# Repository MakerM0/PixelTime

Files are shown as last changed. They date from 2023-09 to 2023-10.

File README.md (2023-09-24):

<p align="center">
    <br>
    
    <br>
</p>
<p align="center">   
    
      
</p>

# [PixelTime](https://oshwhub.com/kakaka/PixelTime)
a low power led watch based on ESP32-C3 & MicroPython

[afdian.net](https://afdian.net/a/modular)    [bilibili](https://www.bilibili.com/video/BV1Bj411i7ZR/)   [OSHWHUB](https://oshwhub.com/kakaka/PixelTime)

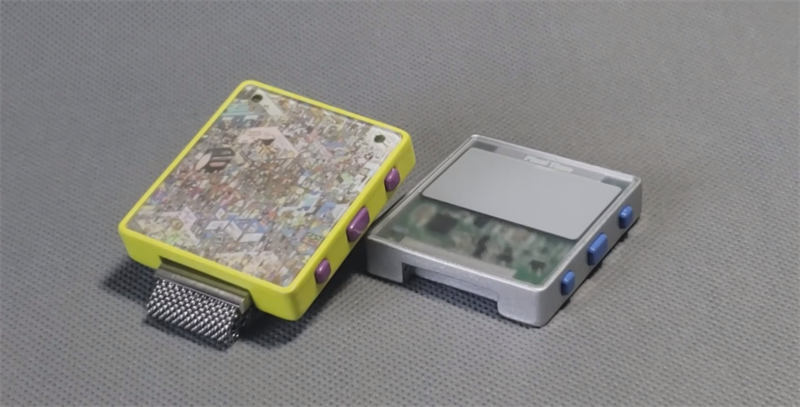
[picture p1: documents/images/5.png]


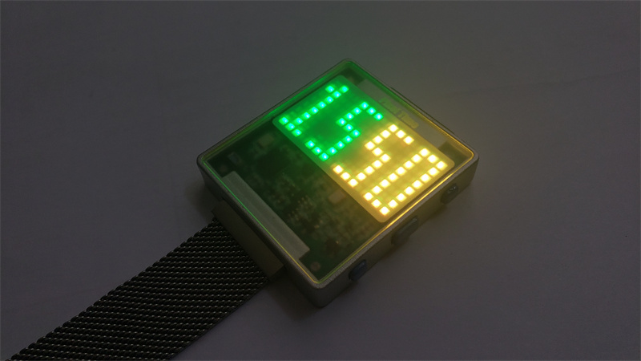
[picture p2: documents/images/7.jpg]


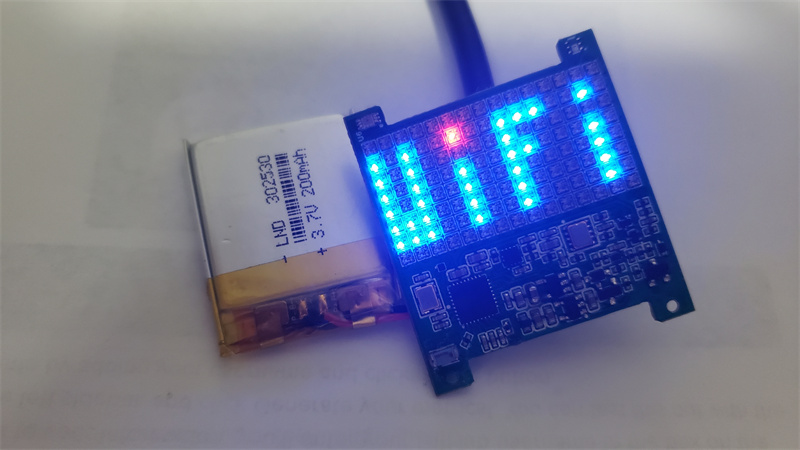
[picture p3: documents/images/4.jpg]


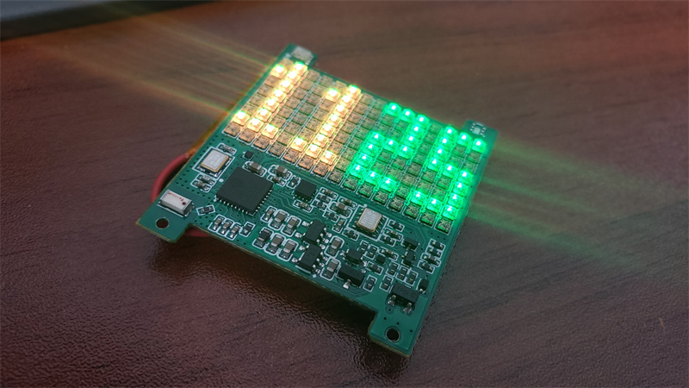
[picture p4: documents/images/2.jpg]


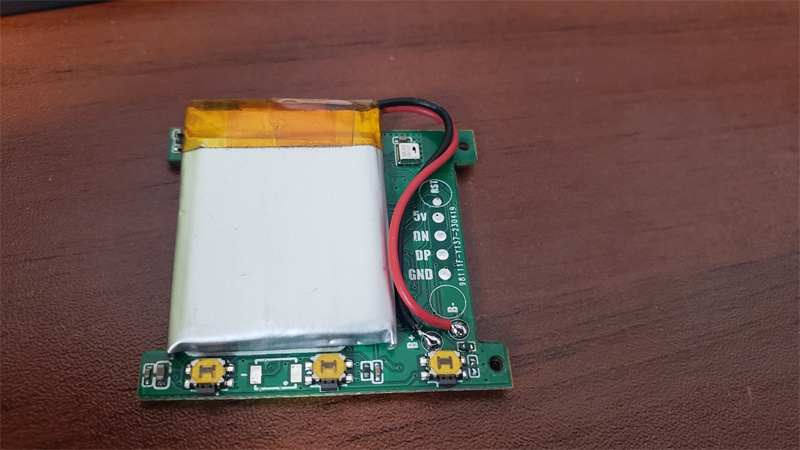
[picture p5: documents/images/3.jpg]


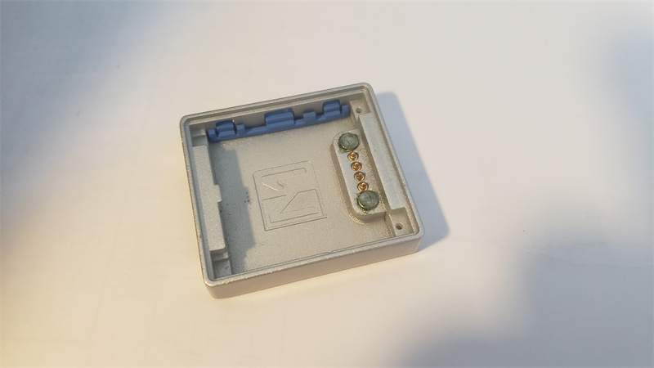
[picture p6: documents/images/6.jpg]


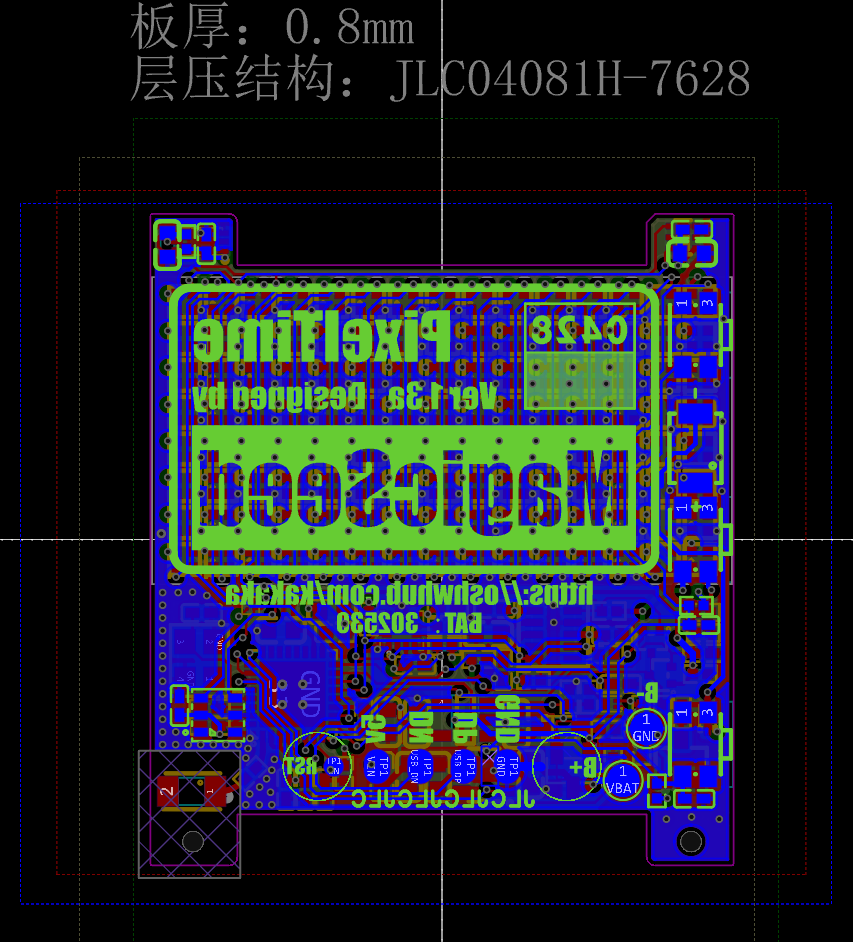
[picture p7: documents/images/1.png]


## Software

based on MicroPython

## Mechanical

## License

(hardware/mechanical)[Creative Commons — Attribution-NonCommercial-ShareAlike 4.0 International — CC BY-NC-SA 4.0](https://creativecommons.org/licenses/by-nc-sa/4.0/)

## Extra

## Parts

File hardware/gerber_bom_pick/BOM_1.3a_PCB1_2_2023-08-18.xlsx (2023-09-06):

No. | Quantity | Designator | Footprint | Manufacturer Part | Manufacturer | Supplier | Supplier Part | Value | Comment | JLCPCB Part Class
1 | 1 | BUZZER2 | BUZ-SMD_L4.0-W3.0-LS4.5-FD | DET402 |  | LCSC | C2911630 |  | DET402 | Extended Part
2 | 2 | C1,C2 | C0402 | 0402CG180J500NT | FH(风华) | LCSC | C1549 | 18pF | 18pF | Basic Part
3 | 13 | C3,C7,C9,C10,C11,C12,C22,C23,C24,C27,C29,C33,C34 | C0402_NEW | CL05B104KO5NNNC | SAMSUNG(三星) | LCSC | C1525 | 100nF | 100nF | Basic Part
4 | 1 | C4 | C0603 | CL10A475KO8NNNC | SAMSUNG(三星) | LCSC | C19666 | 4.7uF | 4.7uF | Basic Part
5 | 6 | C5,C15,C16,C17,C18,C35 | C0603 | CL10A106KP8NNNC | SAMSUNG(三星) | LCSC | C19702 | 10uF | 10uF | Basic Part
6 | 4 | C6,C8,C25,C28 | C0603 | CL10A105KB8NNNC | SAMSUNG(三星) | LCSC | C15849 | 1uF | 1uF | Basic Part
7 | 1 | C30 | C0402 | CL05A105KP5NNNC | SAMSUNG(三星) | LCSC | C14445 | 1uF | 1uF | Extended Part
8 | 2 | C31,C36 | C0402 | CC0402KRX7R7BB104 | YAGEO(国巨) | LCSC | C60474 | 100nF | 100nF | Extended Part
9 | 1 | C37 | C0402 | CL05A475MP5NRNC | SAMSUNG(三星) | LCSC | C23733 | 4.7uF | 4.7uF | Basic Part
10 | 1 | D1 | SOD-323_L1.8-W1.3-LS2.5-RD | 1N5819WS | Hottech(合科泰) | LCSC | C191023 |  | 1N5819WS | Basic Part
11 | 1 | D2 | SOT-523-3_L1.6-W0.8-P1.00-LS1.6-BR | DAN222 | CJ(江苏长电/长晶) | LCSC | C68999 |  | DAN222 | Extended Part
12 | 1 | D3 | SOD-523_L1.2-W0.8-LS1.6-RD | 1N4148WT | onsemi(安森美) | LCSC | C232841 |  | 1N4148WT | Extended Part
13 | 1 | L1 | L0603 | UPZ1608E101-3R0TF | Sunlord(顺络) | LCSC | C96995 |  | UPZ1608E101-3R0TF | Extended Part
14 | 1 | L2 | ANT-SMD_L3.2-W1.6-A | AN3216-245 | rainsun(霖昱微) | LCSC | C2916136 |  | AN3216-245 | Extended Part
15 | 120 | LED1,LED2,LED3,LED4,LED5,LED6,LED7,LED8,LED9,LED10,LED11,LED12,LED13,LED14,LED15,LED16,LED17,LED18,LED19,LED20,LED21,LED22,LED23,LED24,LED25,LED26,LED27,LED28,LED29,LED30,LED31,LED32,LED33,LED34,LED35,LED36,LED37,LED38,LED39,LED40,LED41,LED42,LED43,LED44,LED45,LED46,LED47,LED48,LED49,LED50,LED51,LED52,LED53,LED54,LED55,LED56,LED57,LED58,LED59,LED60,LED61,LED62,LED63,LED64,LED65,LED66,LED67,LED68,LED69,LED70,LED71,LED72,LED73,LED74,LED75,LED76,LED77,LED78,LED79,LED80,LED81,LED82,LED83,LED84,LED85,LED86,LED87,LED88,LED89,LED90,LED91,LED92,LED93,LED94,LED95,LED96,LED97,LED98,LED99,LED100,LED101,LED102,LED103,LED104,LED105,LED106,LED107,LED108,LED109,LED110,LED111,LED112,LED113,LED114,LED115,LED116,LED117,LED118,LED119,LED120 | LED-SMD_4P-L1.5-W1.5 | DY-S1515065/RGBC/6805-5T | TONYU(东裕) | LCSC | C524053 |  | DY-S1515065/RGBC/6805-5T | Extended Part
16 | 1 | Q1 | SOT-25-5_L3.0-W1.8-P0.95-LS3.0-BR | XC6220B331MR-G | TOREX(特瑞仕) | LCSC | C86534 |  | XC6220B331MR-G | Extended Part
17 | 1 | Q2 | SOT-23_L2.9-W1.3-P1.90-LS2.4-BR | AO3400A | BORN伯恩半导体 | LCSC | C344010 |  | AO3400A | Extended Part
18 | 1 | Q3 | SOT-23-3_L2.9-W1.3-P1.90-LS2.4-BR | AO3415 | Hottech(合科泰) | LCSC | C181094 |  | AO3415 | Extended Part
19 | 1 | Q5 | DFN1006-3_L1.0-W0.6-P0.35-BR_BC846BM | HSBG2103 | HUASHUO(华朔) | LCSC | C845598 |  | HSBG2103 | Extended Part
20 | 9 | R1,R2,R7,R12,R14,R15,R22,R24,R25 | R0402 | 0402WGF1002TCE | UNI-ROYAL(厚声) | LCSC | C25744 | 10kΩ | 10kΩ | Basic Part
21 | 3 | R3,R10,R11 | R0402 | 0402WGF0000TCE | UNI-ROYAL(厚声) | LCSC | C17168 | 0Ω | 0Ω | Basic Part
22 | 2 | R5,R6 | R0402 | 0402WGF1001TCE | UNI-ROYAL(厚声) | LCSC | C11702 | 1kΩ | 1kΩ | Basic Part
23 | 3 | R8,R17,R18 | R0402 | 0402WGF1003TCE | UNI-ROYAL(厚声) | LCSC | C25741 | 100kΩ | 100kΩ | Basic Part
24 | 2 | R13,R27 | R0402 | 0402WGF4703TCE | UNI-ROYAL(厚声) | LCSC | C25790 | 470kΩ | 470kΩ | Basic Part
25 | 1 | R16 | R0402 | 0402WGF200JTCE | UNI-ROYAL(厚声) | LCSC | C25089 | 20Ω | 20Ω | Extended Part
26 | 2 | R23,R28 | R0402 | 0402WGF1004TCE | UNI-ROYAL(厚声) | LCSC | C26083 | 1MΩ | 1MΩ | Basic Part
27 | 1 | R29 | R0402 | 0402WGF3001TCE | UNI-ROYAL(厚声) | LCSC | C25784 |  | 0402WGF3001TCE | Extended Part
28 | 3 | SW1,SW2,SW3 | SW-SMD_ST-1186BM | ST-1186BM | RISHENG(日昇) | LCSC | C589196 |  | ST-1186BM | Extended Part
29 | 1 | U1 | QFN-32_L5.0-W5.0-P0.50-TL-EP3.7 | ESP32-C3FH4 | ESPRESSIF 乐鑫 | LCSC | C2858491 |  | ESP32-C3FH4 | Extended Part
30 | 1 | U2 | SENSOR-SMD_L3.0-W3.0-P1.00-BR | AHT20 | 广州奥松 | LCSC | C2757850 |  | AHT20 | Extended Part
31 | 1 | U3 | LGA-12_L2.0-W2.0-P0.50-BL | KXTJ3-1057 | ROHM(罗姆) | LCSC | C442603 |  | KXTJ3-1057 | Extended Part
32 | 1 | U4 | SOT-23-5_L3.0-W1.7-P0.95-LS2.8-BR | TP4054-42-SOT25R | TOPPOWER(南京拓微) | LCSC | C32574 |  | TP4054-42-SOT25R | Basic Part
33 | 1 | U6 | WSOF-6_L2.6-W1.6-P0.50-BL | BH1715FVC-TR | ROHM(罗姆) | LCSC | C79632 |  | BH1715FVC-TR | Extended Part
34 | 1 | U7 | WLCSP-4_L0.8-W0.8-R2-C2-P0.40-BL | QMC6308 | QST(上海矽睿) | LCSC | C462705 |  | QMC6308 | Extended Part
35 | 1 | U9 | OSC-SMD_10P-L3.2-W2.5-BL-1 | RX8111CE | EPSON(爱普生) | LCSC | C2929261 |  | RX8111CE | Extended Part
36 | 1 | U11 | SENSOR-SMD_LTR-390UV-01 | LTR-390UV-01 | LITEON(台湾光宝) | LCSC | C492374 |  | LTR-390UV-01 | Extended Part
37 | 1 | X1 | OSC-SMD_4P-L3.2-W2.5-BL_SIT8008BI | X322540MPB4SI | YXC扬兴科技 | LCSC | C9010 | 40MHz | 40MHz | Extended Part

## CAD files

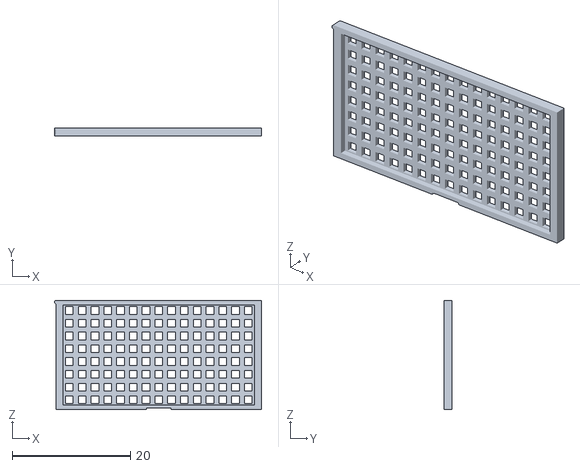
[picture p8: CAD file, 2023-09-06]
mechanical/stl/压板.stl
34.9 x 1.35 x 18.5

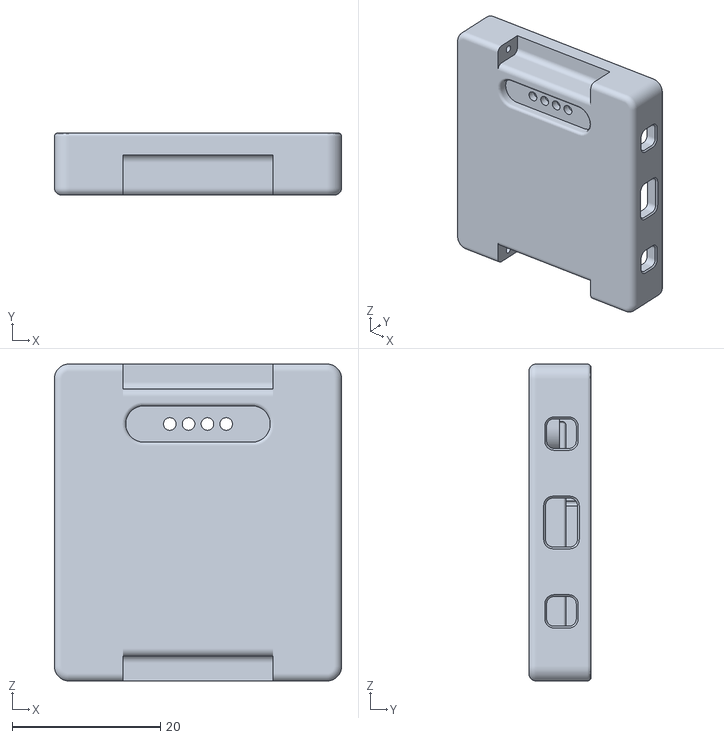
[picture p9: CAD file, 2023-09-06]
mechanical/stl/外壳.stl
38.8 x 8.40 x 42.8

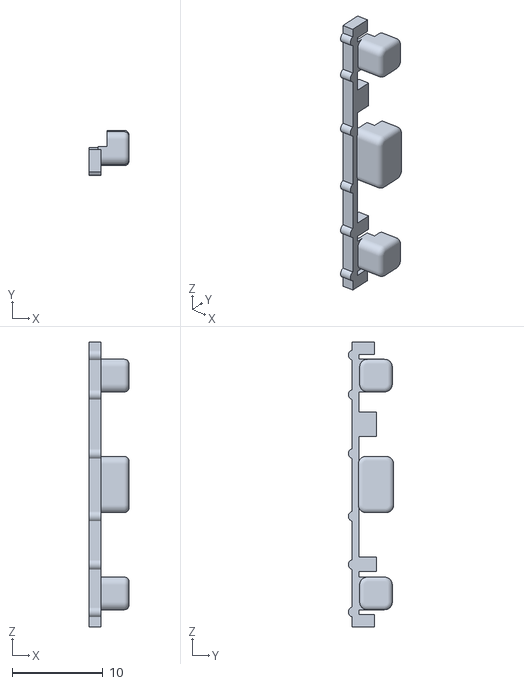
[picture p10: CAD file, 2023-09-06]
mechanical/stl/按键.stl
4.40 x 5.00 x 31.4

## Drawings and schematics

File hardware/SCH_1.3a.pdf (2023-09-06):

Ambient Light | ACC | UV

# Magnetic

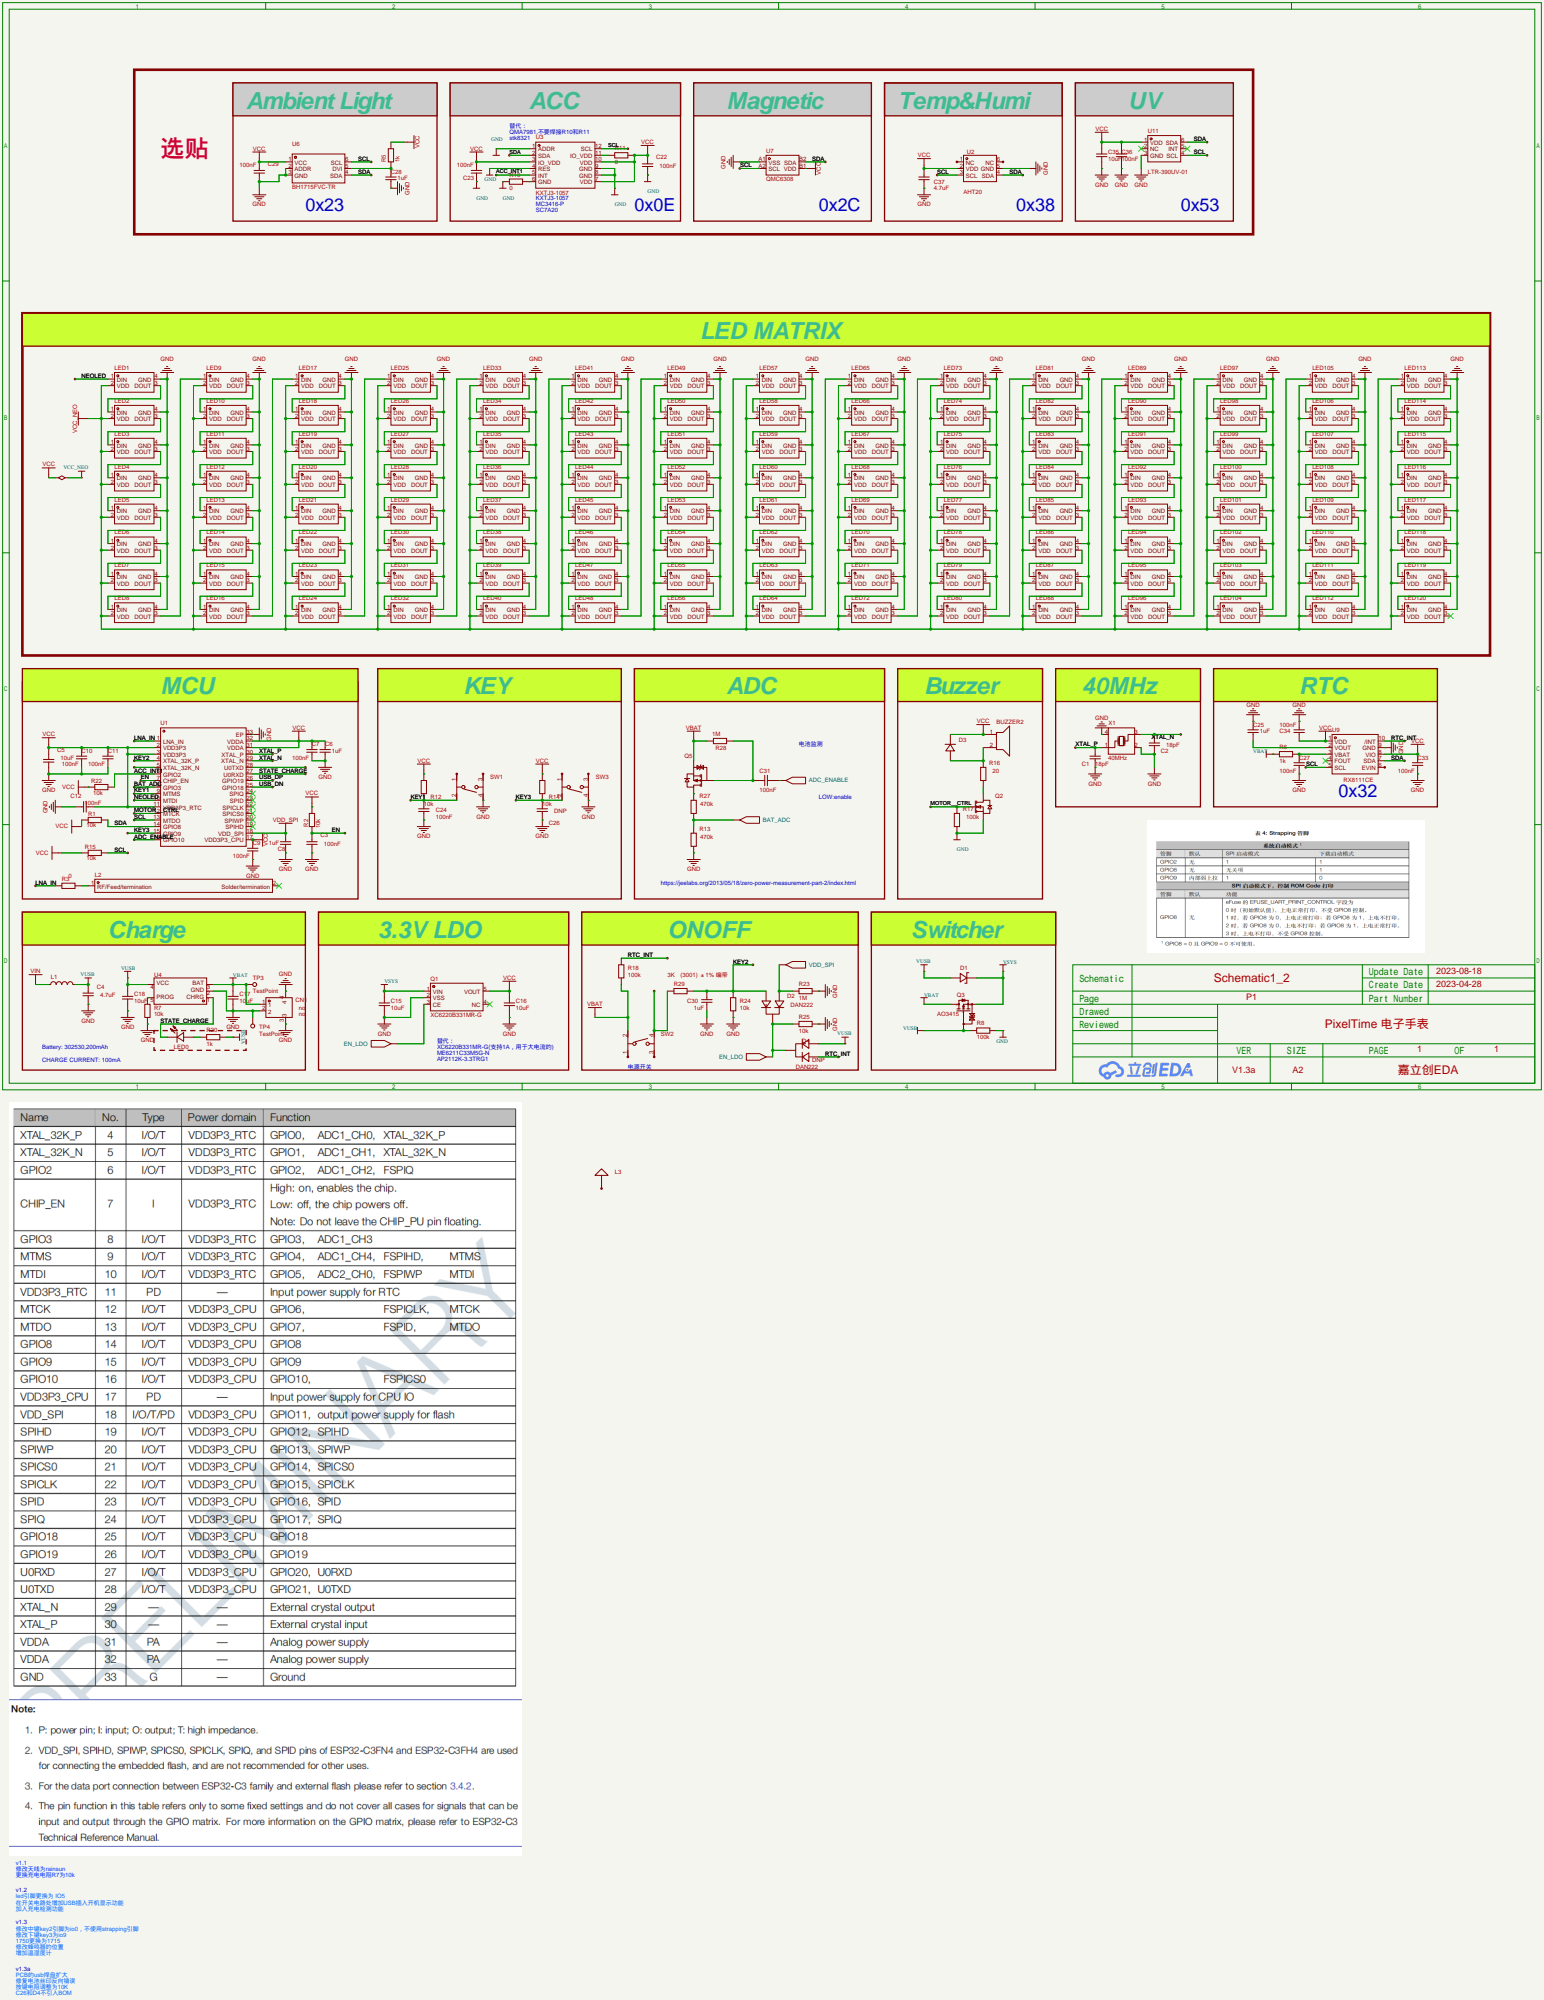
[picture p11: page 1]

https://jeelabs.org/2013/05/18/zero-power-measurement-part-2/index.html

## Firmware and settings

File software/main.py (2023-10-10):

 
from machine import I2C, Pin
import time
import network 
import neopixel 
import gc
import bitmapfont
from font3x8 import *
from week7x7  import * 
import rx8111

import config

ssid = config.ssid
password =config.password

zonetime = 8*3600

NEOPIXEL_PIN = 5
ROWS = 8
COLS = 15
NUMBER_PIXELS = ROWS * COLS

C_BLACK=(0,0,0)
C_GREEN=(0,35,0)
C_BLUE=(0,0,35)
C_RED=(35,0,0)
C_YELLOW=(35,35,0)   
C_MONTH=(31,5,12) 
C_DAY=(35,31,31) 

np = neopixel.NeoPixel(Pin(NEOPIXEL_PIN), NUMBER_PIXELS)




#15x8
ICON_WIFI=(
    0,0,0,0,0,0,0,0,0,0,0,0,0,0,0,
    1,0,1,0,0,1,0,0,1,1,1,0,0,1,0,
    1,0,1,0,0,0,0,0,1,0,0,0,0,0,0,
    1,0,1,0,0,1,0,0,1,1,0,0,0,1,0,
    1,0,1,0,0,1,0,0,1,0,0,0,0,1,0,
    1,1,1,0,0,1,0,0,1,0,0,0,0,1,0,
    1,1,1,0,0,1,0,0,1,0,0,0,0,1,0,
    0,0,0,0,0,0,0,0,0,0,0,0,0,0,0,

)
 
class Display(object):
    def __init__(self,np):
        self.np=np

    
    def write_pixel(self,x,y,value):
        if y >= 0 and y < ROWS and x >=0 and x < COLS:
            self.np[x*ROWS + y] = value

    def drawPixel(self,x,y,value):
        self.write_pixel(x,y,value)

        
            
    def clear(self):
        for i in range(NUMBER_PIXELS):
            np[i]=(0,0,0)            
        self.np.write()
    
    def show(self):
        self.np.write()

    def draw1Num(self,x,y,num,color,bg=None):
        num=num%10
        for j in range(8):
            for i in range(3):
                if  FONT3X8[num][i+j*3]==1:
                    self.write_pixel(x+i,y+j,color)
                else :
                    if bg != None:
                        self.write_pixel(x+i,y+j,bg)
                    
    def drawNum(self,x,y,num,color,bg=None)  :
        self.draw1Num(x,y,num//1000%10,color,bg)
        self.draw1Num(x+4,y,num%1000//100,color,bg)
        self.draw1Num(x+4*2,y,num%100//10,color,bg)
        self.draw1Num(x+4*3,y,num%10,color,bg)
        
    def change1Num(self,x,y,num_src,num_dest,color,bg=None):
        num_src=num_src%10
        num_dest=num_dest%10
        
        for i in range(1,9):
            self.draw1Num(x,y-i,num_src,color,bg)
            self.draw1Num(x,y+8-i,num_dest,color,bg)
            time.sleep(0.01)
            self.show()
    
    def draw1Week(self,x,y,num,color,bg=None):   
        for j in range(8):
            for i in range(7):
                if  WEEK7X8[num][i+j*7]==1:
                    self.write_pixel(x+i,y+j,color)
                else :
                    if bg != None:
                        self.write_pixel(x+i,y+j,bg)
    
    def drawWeek(self,x,y,watch,color,bg=None)  :
        # num=num%7
        # print(num)
        self.draw1Week(x,y,7,color,bg)
        self.draw1Week(x+8,y,watch.time_now[6],color,bg) 
    
    def drawTime(self,x,y,watch,color1,color2,bg=None): 
        self.draw1Num(x+0,y,watch.time_now[3]//10,color1,bg)
        self.draw1Num(x+4,y,watch.time_now[3]%10,color1,bg)
        self.draw1Num(x+8,y,watch.time_now[4]//10,color2,bg)
        self.draw1Num(x+12,y,watch.time_now[4]%10,color2,bg)
        self.show()
    
    def drawDate(self,x,y,watch,color1,color2,bg=None):
        if  watch.time_now[1]//10:
            self.draw1Num(x+0,y,watch.time_now[1]//10,color1,bg)
        else:
            self.draw1Num(x+0,y,watch.time_now[1]//10,bg,bg)

        self.draw1Num(x+4,y,watch.time_now[1]%10,color1,bg)
        if  watch.time_now[2]//10:            
            self.draw1Num(x+8,y,watch.time_now[2]//10,color2,bg)
        else:
            self.draw1Num(x+8,y,watch.time_now[2]//10,bg,bg)
        self.draw1Num(x+12,y,watch.time_now[2]%10,color2,bg)
        self.show()
    
    def drawIcon(self,x,y,width,height,icon,color,bg=None):
        for j in range(height):
            for i in range(width):
                if  icon[i+j*width]==1:
                    self.write_pixel(x+i,y+j,color)
                else :
                    if bg != None:
                        self.write_pixel(x+i,y+j,bg)




disp = Display(np)

import machine
class Watch(object):
    def __init__(self,time_now):
        self.time_now=time_now
        self.time_old=time_now
        self.timeout=0 #关机超时时间，ms单位
        self.timeout_stamp=time.ticks_ms()
        

    def resetTimeout(self,timeout=5000):
        self.timeout= timeout
        self.timeout_stamp=time.ticks_ms()

    def checkTimeout(self): 
        deadline = time.ticks_add(self.timeout_stamp,  self.timeout)
        if time.ticks_diff(deadline, time.ticks_ms()) > 0:
            return False
        else:
             return True


    

     

    def poweroff(self):
        machine.deepsleep()


    


INDEX_HOUR = 3
INDEX_MINUTE = 4
INDEX_SECOND = 5

 

def updateTime(watch):
    watch.time_now = rtc.datetime()
    if watch.time_now != watch.time_old:
        if watch.time_now[INDEX_MINUTE]%10 != watch.time_old[INDEX_MINUTE]%10:
            disp.change1Num(12,0,watch.time_old[INDEX_MINUTE]%10,watch.time_now[INDEX_MINUTE]%10,C_YELLOW,C_BLACK)
            
        if watch.time_now[INDEX_MINUTE]//10 != watch.time_old[INDEX_MINUTE]//10:
            disp.change1Num(8,0,watch.time_old[INDEX_MINUTE]//10,watch.time_now[INDEX_MINUTE]//10,C_YELLOW,C_BLACK)
            
        if watch.time_now[INDEX_HOUR]%10 != watch.time_old[INDEX_HOUR]%10:
            disp.change1Num(4,0,watch.time_old[INDEX_HOUR]%10,watch.time_now[INDEX_HOUR]%10,C_GREEN,C_BLACK)
            
        if watch.time_now[INDEX_HOUR]//10 != watch.time_old[INDEX_HOUR]//10:
            disp.change1Num(0,0,watch.time_old[INDEX_HOUR]//10,watch.time_now[INDEX_HOUR]//10,C_GREEN,C_BLACK)
        
        watch.time_old = watch.time_now


print('rx8111 test')
i2c = I2C(0, scl=Pin(7), sda=Pin(8), freq=400000)
rtc = rx8111.RX8111(i2c)

week=('SUN','MON','TUE','WED','THU','FRI','SAT')
 


def syncTimeByWifi(ssid,password,trycnt=20):
    if ssid == None :
        return
    import ntptime
    wlan = network.WLAN(network.STA_IF)
    wlan.active(True)
    wlan.connect(ssid,password)
    
    if not wlan.isconnected():
        while not wlan.isconnected():
            print("Waiting to connect:")
            time.sleep(1.0)
            trycnt = trycnt-1
            if trycnt%2 :
                disp.drawPixel(5,1,C_GREEN)
            else:
                disp.drawPixel(5,1,C_RED)

            disp.show()
            if trycnt<0:
                print("\nFail !!!\n")
                break
    if wlan.isconnected():     
        print(wlan.ifconfig())
        while True:
            try:
                print('获取时间中')
                ntptime.host = 'ntp1.aliyun.com'
                ntptime.settime()
                print('成功获取')
                break
            except:
                print('获取失败')
                time.sleep(1)
    wlan.disconnect()
    wlan.active(False)
    watch.resetTimeout()



charge = Pin(20, Pin.IN, Pin.PULL_UP)

k1 = Pin(4, Pin.IN)
k2 = Pin(0, Pin.IN)
k3 = Pin(9, Pin.IN)


class Event():
    K1_PRESSED=1
    K1_RELEASED=2
    K2_PRESSED=3
    K2_RELEASED=4
    K3_PRESSED=5
    K3_RELEASED=6
    K1_LONG=7
    K2_LONG=8
    K3_LONG=9

    def __init__(self):
        self.event=[]
    
    def addEvent(self,evt):
        self.event.append(evt)
    
    def getEvent(self):  
        if len(self.event)==0:
            return -1              
        return self.event.pop(0)

LongPressed = 1000       
key_time=0
def fun(key):
    global key_time
    watch.resetTimeout()
    if key==k1:
        if key.value() == 0:
            key_time=time.ticks_ms()
            # print('k1 pressed')
            evt.addEvent(Event.K1_PRESSED) 
        else:
            # print('k1 released')
            if time.ticks_diff(time.ticks_ms(),key_time)>LongPressed:
                evt.addEvent(Event.K1_LONG)
            else:                
                evt.addEvent(Event.K1_RELEASED)
    if key==k2:
        if key.value() == 1:
            # print('k2 pressed')
            evt.addEvent(Event.K2_PRESSED)
        else:
            # print('k2 released')
            evt.addEvent(Event.K2_RELEASED)
    if key==k3:
        if key.value() == 0:
            # print('k3 pressed')
            evt.addEvent(Event.K3_PRESSED)
        else:
            # print('k3 released')   
            evt.addEvent(Event.K3_RELEASED)  
    




k1.irq(fun,Pin.IRQ_FALLING | Pin.IRQ_RISING)
k2.irq(fun,Pin.IRQ_FALLING | Pin.IRQ_RISING)
k3.irq(fun,Pin.IRQ_FALLING | Pin.IRQ_RISING)

currentPage=0


  

# syncTimeByWifi(ssid,password)
# sec=time.mktime(time.localtime())#获取时间戳
# now = time.localtime(sec+zonetime)#获取新时区的时间

# rtc.datetime(now)

evt = Event() 
disp.clear()
 
watch = Watch(rtc.datetime())
 
disp.drawTime( 0,0,watch,C_GREEN,C_YELLOW,C_BLACK)

watch.resetTimeout()

def switchPage():
    global currentPage
    if currentPage==0:
        
        for j in range(8):
            disp.drawTime(0,-1-j,watch,C_GREEN,C_YELLOW,C_BLACK)
            disp.drawWeek(0,7-j,watch,C_GREEN,C_BLACK)
            disp.show()
            time.sleep(0.01)
        currentPage=1
        print(currentPage)
        return

    if currentPage==1:
        for j in range(8):
            disp.drawWeek(0,-1-j,watch,C_GREEN,C_BLACK)
            disp.drawDate(0,7-j,watch,C_MONTH,C_DAY,C_BLACK)
            disp.show()
            time.sleep(0.01)
        currentPage=2
        print(currentPage)
        return

    if currentPage==2:
        for j in range(8):
            disp.drawDate(0,-1-j,watch,C_MONTH,C_DAY,C_BLACK)
            disp.drawTime(0,7-j,watch,C_GREEN,C_YELLOW,C_BLACK)
            disp.show()
            time.sleep(0.01)
        currentPage=0
        print(currentPage)
        return

def handleEvent(evt):
    global currentPage     
    if  evt<=0:
        return
    
    if evt==Event.K2_PRESSED:
        switchPage()
        pass
    if evt==Event.K3_PRESSED:
        watch.poweroff()

    if evt==Event.K1_LONG:
        print('syncTimeByWifi')
 
        disp.drawIcon(0,0,15,8,ICON_WIFI,C_BLUE,C_BLACK)
        disp.show()
        syncTimeByWifi(ssid,password)
        sec=time.mktime(time.localtime())#获取时间戳
        now = time.localtime(sec+zonetime)#获取新时区的时间

        rtc.datetime(now)
        if currentPage ==0:
            disp.drawTime(0,0,watch,C_GREEN,C_YELLOW,C_BLACK)            
            updateTime(watch) 
        elif currentPage ==1:
            disp.drawWeek(0,0,watch,C_GREEN,C_BLACK)
        elif currentPage ==2:
            disp.drawDate(0,0,watch,C_MONTH,C_DAY,C_BLACK)

        disp.show()

        print(now)
        pass

 
 
timeout_en = False

if  charge.value()==0 :
    timeout_en = False
else:
    timeout_en = True


print(timeout_en)

 


while True:
    if  charge.value()==0 :
        time.sleep(1.0)
        disp.clear()
        
    if  watch.checkTimeout() and timeout_en:
        print("timeout")
        watch.poweroff()
        watch.resetTimeout()
     

    handleEvent(evt.getEvent())
    # Calculate deadline for operation and test for it
    deadline = time.ticks_add(time.ticks_ms(), 5000)
    if time.ticks_diff(deadline, time.ticks_ms()) > 0:
        deadline = time.ticks_add(time.ticks_ms(), 5000)
        if currentPage ==0:
            updateTime(watch)

         
    
        # print(watch.time_now)
    time.sleep(0.2)
    gc.collect()
    # print(f'mem: {gc.mem_free()}')

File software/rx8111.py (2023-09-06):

'''
    RX8111 RTC drive
 
    Author: M0dular
    Date:   2023-8-5
    Ver:    0.1.0
 
    https://oshwhub.com/kakaka
'''



from micropython import const
from math import log2
from gc import collect
# bus address 
RX8111_ADDR = const(0x32)

# Basic time and calendar register 
RX8111_SEC = const(0x10)
RX8111_MIN = const(0x11)
RX8111_HOUR = const(0x12)
RX8111_WEEK = const(0x13)
RX8111_DAY = const(0x14)
RX8111_MONTH = const(0x15)
RX8111_YEAR = const(0x16)
RX8111_MIN_ALARM = const(0x17)
RX8111_HOUR_ALARM = const(0x18)
RX8111_WEEK_DAY_ALARM = const(0x19)
RX8111_TIMER_COUNTER0 = const(0x1A)
RX8111_TIMER_COUNTER1 = const(0x1B)
RX8111_TIMER_COUNTER2 = const(0x1C)
RX8111_EXTENREG = const(0x1D)
RX8111_FLAGREG = const(0x1E)
RX8111_CTRLREG = const(0x1F)

RX8111_TIMESTAMP_1_1000S = const(0x20)
RX8111_TIMESTAMP_1_100S = const(0x21)
RX8111_TIMESTAMP_SEC = const(0x22)
RX8111_TIMESTAMP_MIN = const(0x23)
RX8111_TIMESTAMP_HOUR = const(0x24)
RX8111_TIMESTAMP_WEEK = const(0x25)
RX8111_TIMESTAMP_DAY = const(0x26)
RX8111_TIMESTAMP_MONTHS = const(0x27)
RX8111_TIMESTAMP_YEAR = const(0x28)
RX8111_STATUS_STAMP = const(0x29)

RX8111_EVIN_SETTING = const(0x2B)
RX8111_SEC_ALARM = const(0x2C)
RX8111_TIMER_CONTROL = const(0x2D)
RX8111_CMD_TRIG_CTRL = const(0x2E)
RX8111_COMMAND_TRIGGER = const(0x2F)

RX8111_PWR_SWITCH_CTRL = const(0x32)
RX8111_STATUS_MONITOR = const(0x33)
RX8111_TIME_STAMP_BUF_CTRL = const(0x34)
RX8111_TIME_STAMP_TRIG_CTRL = const(0x35)
RX8111_TIME_STAMP_DATA_STATUS = const(0x36)

'''
RX8111_EXT_TSEL0 BIT(0)
RX8111_EXT_TSEL1 BIT(1)
RX8111_EXT_ECP BIT(2)
RX8111_EXT_WADA BIT(3)
RX8111_EXT_TE BIT(4)
RX8111_EXT_USEL BIT(5)
RX8111_EXT_FSEL0 BIT(6)
RX8111_EXT_FSEL1 BIT(7)

RX8111_FLAG_FSTOPF BIT(0)
RX8111_FLAG_VLF BIT(1)
RX8111_FLAG_EVF BIT(2)
RX8111_FLAG_AF BIT(3)
RX8111_FLAG_TF BIT(4)
RX8111_FLAG_UF BIT(5)
RX8111_FLAG_PORF BIT(7)
'''
RX8111_CTRL_STOP =const(0)
'''
RX8111_CTRL_EIE BIT(2)
RX8111_CTRL_AIE BIT(3)
RX8111_CTRL_TIE BIT(4)
RX8111_CTRL_UIE BIT(5)

RX8111_EVIN_EOVEN BIT(1)
RX8111_EVIN_EPRUP_SEL0 BIT(2)
RX8111_EVIN_EPRUP_SEL1 BIT(3)
RX8111_EVIN_EPRDW_SEL BIT(4)
RX8111_EVIN_ET0 BIT(5)
RX8111_EVIN_ET1 BIT(6)
RX8111_EVIN_EHL BIT(7)

RX8111_TIMER_CTRL_TSTP BIT(0)
RX8111_TIMER_CTRL_TMPIN BIT(1)
RX8111_TIMER_CTRL_TBKE BIT(2)
RX8111_TIMER_CTRL_TBKON BIT(3)

RX8111_CMD_TRIG_DUMMY0 BIT(0)
RX8111_CMD_TRIG_DUMMY1 BIT(1)
RX8111_CMD_TRIG_DUMMY2 BIT(2)
RX8111_CMD_TRIG_DUMMY3 BIT(3)
RX8111_CMD_TRIG_DUMMY4 BIT(4)
RX8111_CMD_TRIG_DUMMY5 BIT(5)
RX8111_CMD_TRIG_DUMMY6 BIT(6)
RX8111_CMD_TRIG_DUMMY7 BIT(7)

RX8111_PSC_SMP_TSEL0 BIT(0)
RX8111_PSC_SMP_TSEL1 BIT(1)
RX8111_PSC_SMP_SWSEL0 BIT(2)
RX8111_PSC_SMP_SWSEL1 BIT(3)
RX8111_PSC_SMP_INIEN BIT(6)
RX8111_PSC_SMP_CHGEN BIT(7)

RX8111_PSC_SMP_CHGEN BIT(7)

RX8111_STAT_M_FVLOW BIT(1)
RX8111_STAT_M_FVCMP BIT(3)
RX8111_STAT_M_EVINMON BIT(6)
# Insert and Defined ALARM_AE 
RX8111_ALARM_AE BIT(7)

'''

class RX8111(object):
    def __init__(self,i2c):
        self.i2c = i2c
        self.tb = bytearray(1)
        self.rb = bytearray(1)
        self.buf = bytearray(7)
        self.DT = [0] * 7
        # if RX8111_ADDR in self.i2c.scan():
        #     print('RTC: rx8111 find at address: 0x%x ' %(RX8111_ADDR))
        # else:
        #     print('RTC: rx8111 not found at address: 0x%x ' %(RX8111_ADDR))
        # collect() # 

    # set reg
    def	setReg(self, reg, dat):
        self.tb[0] = dat
        self.i2c.writeto_mem(RX8111_ADDR, reg, self.tb)

    # get reg
    def	getReg(self, reg):
        self.i2c.readfrom_mem_into(RX8111_ADDR, reg, self.rb)
        return self.rb[0]


    # 将二进制编码的十进制数转换为普通十进制数
    def _bcd2dec(self, bcd) :
        """Convert binary coded decimal (BCD) format to decimal"""
        return (((bcd & 0xf0) >> 4) * 10 + (bcd & 0x0f))

    # 将十进制编码的二进制数转换为普通十进制数
    def _dec2bcd(self, dec):
        """Convert decimal to binary coded decimal (BCD) format"""
        tens, units = divmod(dec, 10)
        return (tens << 4) + units

    def WeekToBdc(self, val) :
        return 0x01 << val
 

    def WeekToNum(self, val) :
        return int(log2(val))

    
 
    def setBit(self, reg,  bit_addr):
        
        data = self.getReg(reg)
        data |= (0x01 << bit_addr)

        self.setReg(reg, data)
 

    def clearBit(self, reg,  bit_addr):
         
        data = self.getReg(reg)
        data &= ~(0x01 << bit_addr)

        self.setReg(reg, data)
 
    def datetime(self,DT=None):
        '''
            DT: year,month,day,hour,minute,second,weekday
            在Python的time.localtime()函数中，stars from Monday (0) and ends on Sunday (6)。所以星期从0开始计数，0代表星期一。
            而rx8111是从星期日开始计数，0代表星期日
            Sunday    0 0 0 0 0 0 0 1 01 h
            Monday    0 0 0 0 0 0 1 0 02 h
            Tuesday   0 0 0 0 0 1 0 0 04 h
            Wednesday 0 0 0 0 1 0 0 0 08 h
            Thursday  0 0 0 1 0 0 0 0 10 h
            Friday    0 0 1 0 0 0 0 0 20 h
            Saturday  0 1 0 0 0 0 0 0 40 h
        '''
        if DT==None:
            self.i2c.readfrom_mem_into(RX8111_ADDR, RX8111_SEC, self.buf)
            
            self.DT[0] = self._bcd2dec(self.buf[6]) + 2000 # year
            self.DT[1] = self._bcd2dec(self.buf[5]& 0x1F)# month
            self.DT[2] = self._bcd2dec(self.buf[4] & 0x3F)#  day            

            self.DT[3] = self._bcd2dec(self.buf[2] & 0x3F)#  hour
            self.DT[4] = self._bcd2dec(self.buf[1]& 0x7F)# minute
            self.DT[5] = self._bcd2dec(self.buf[0]& 0x7F)# second
            
            self.DT[6] = self.WeekToNum(self.buf[3]) # week day

            return tuple(self.DT)
        else:
            self.setBit(RX8111_CTRLREG, RX8111_CTRL_STOP)
            self.setReg(RX8111_FLAGREG, 0x00)
            
            self.buf[6] = self._dec2bcd(DT[0]%100)   # year
            self.buf[5] = self._dec2bcd(DT[1]%13)    # month
            self.buf[4] = self._dec2bcd(DT[2]%32)    # day
            
            self.buf[2] = self._dec2bcd(DT[3]%24)    # hour
            self.buf[1] = self._dec2bcd(DT[4]%60)    # minute
            self.buf[0] = self._dec2bcd(DT[5]%60)    # second
            
            self.buf[3] = self.WeekToBdc((DT[6]+1)%7)     # week day
            
            self.i2c.writeto_mem(RX8111_ADDR, RX8111_SEC, self.buf) 

            self.clearBit(RX8111_CTRLREG, RX8111_CTRL_STOP)



 

if __name__ == "__main__":
    from machine import I2C, Pin
    import time
    print('rx8111 test')
    i2c = I2C(0, scl=Pin(7), sda=Pin(8), freq=400000)
    rtc = RX8111(i2c)
    rtc.datetime((2023,8,5,16,25,59,6))
    while True:
        print(rtc.datetime())
        time.sleep(1.0)
